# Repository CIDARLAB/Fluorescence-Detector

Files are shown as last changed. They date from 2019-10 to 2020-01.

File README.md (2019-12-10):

Fluorescence Detector

# Contents

1. Lockin-Amplifier - Full implementation of the Fluorescence Detector System
2. ADC Test Board - Test Board and default in sister board for ADC for V1 of the Lockin-Amplifier
3. Mod-Demod Test Board - Test board for the demodulator testing
4. Light Source Modulator Board - Board for Modulating the Light Source (LED/Laser)

# Locking Amplifier Specs

| Parameter 	| Value 	|
|---	|---	|
| #Channels 	| 1 	|
| Max Sampling Rate 	| 2.5 kHz 	|
| Amplification 	| x10^8 (140 dB) 	|
| SNR 	| TBA 	|
| Input Voltage Noise 	| TBA 	|
| Input Impedance 	| TBA 	|
| Voltage Sensitivity Range 	| TBA to TBA 	|
| Minimum Step Size 	| TBA 	|
| ADC Resolution 	| 16 bit 	|
| ADC Interface 	| SPI (2 wire) 	|
| Supply Voltage 	| 24 V 	|
| Supply Current 	| 300 mA 	|
| Supply Pin 	| 2.5 mm Barrel Jack 	|

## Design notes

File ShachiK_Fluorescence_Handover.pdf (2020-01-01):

## Fluorescence Detector on Chip Handover Notes

Shachi Khadilkar
Ph.: 6173787579
Email: shachivk@bu.edu

The Fluorescence detector on chip uses a lock-in amplification technique to amplify weak fluorescent signals obscured by noise. The object of this text is to briefly describe the different parts of this system and how to use them.

Big picture:

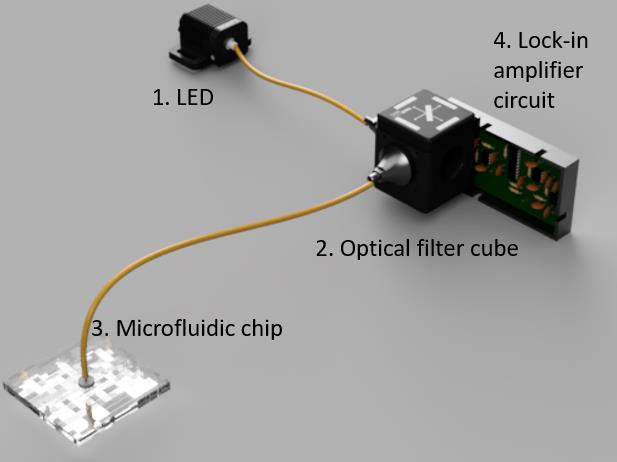
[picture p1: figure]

Electronics:

Lock-in amplification requires a modulated light source, pre-amplifiers and a demodulator + low pass filter circuit. Three PCBs were made – an LED modulator, a lock-in amplifier and an A to D board.

Lock-in amplifier PCB:

Components:
1. TL081 (4 ICs) – operational amplifiers
2. AD630 (1 IC) – Demodulator
3. Photodiode (1) – BPW21
4. Passives
5. Screw Terminals
6. Test points

Lock-in amplifier v1.1:

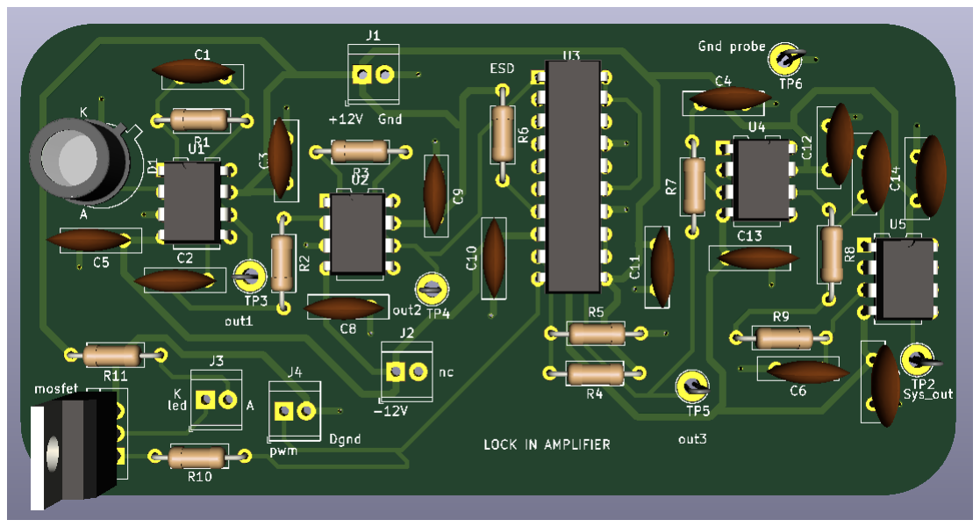
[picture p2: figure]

Using the board:

- Connect the power supply in series mode and supply power to the board at screw terminals with appropriate marking (+12V, -12V, Gnd). DO NOT exceed +-18V.
- Fluorescent light incident on the photodiode is the signal input to the PCB.
- The demodulator needs a PWM signal (at the screw term marked accordingly). Connect the Arduino ground to the Dgnd pin on the PCB. PWM signal is 5kHz, 10 % duty cycle for the current design.
- Output signal is obtained at test point Sys_out (or Final o/p for v1.2).
If the output signal is being measured by an oscilloscope, connect the scope probe to Sys_out and the ground clip to the test point labelled Gnd probe.
If ADC is used, connect Sys_out to ADC
- The test-point after each stage can be used for hardware debugging.

Lock-in amplifier v1.2:

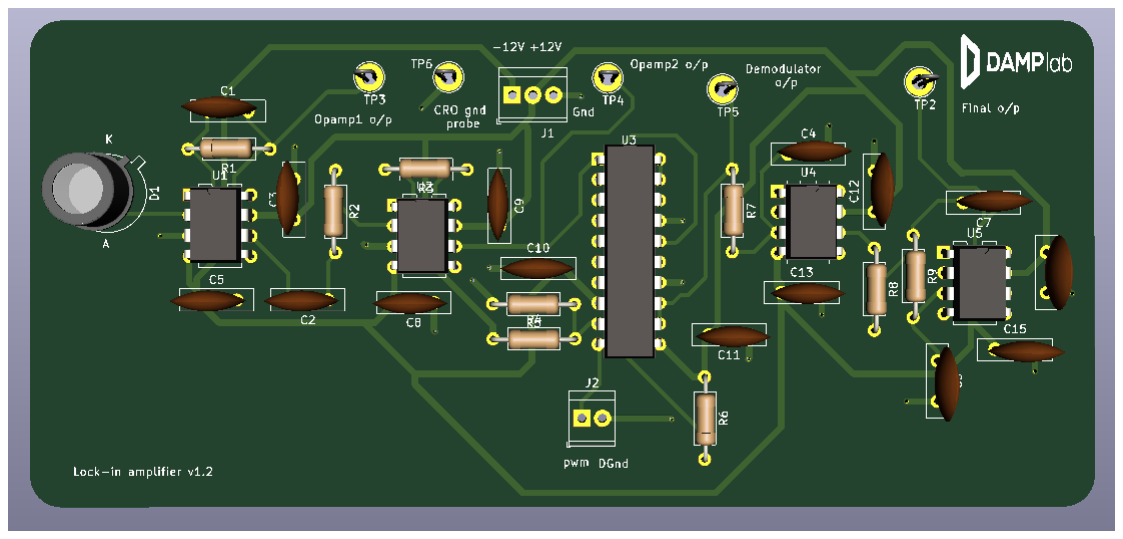
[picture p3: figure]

Using the board:

- Similar to v1.1.

A to D Converter:

Components:
1. AD8517 (1 IC) – A/D converter
2. OPA132 (1 IC) – Operational amplifier
3. Passives
4. Screw terminals

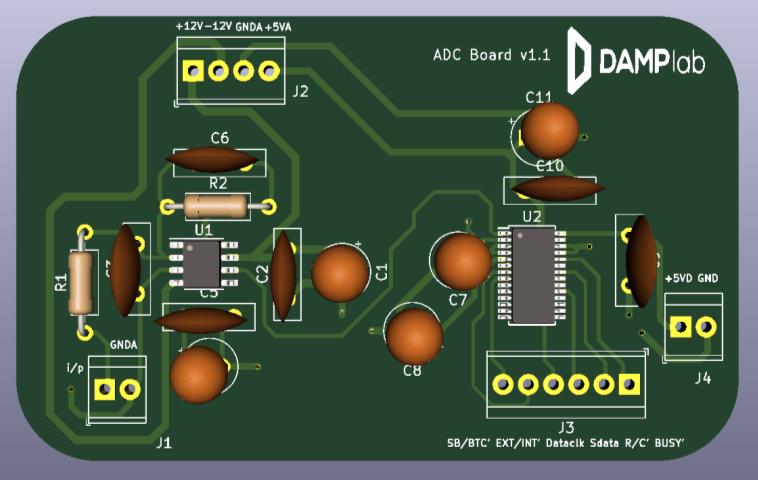
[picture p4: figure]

Using the board:

- Connect Sys_out (or Final o/p) of the lock-in amplifier board to appropriate screw terminal (marked i/p) for ADC analog input.
- Supply +-12V, ground, +5V analog and +1.8V digital power inputs to the board at the appropriate screw terminals. (Use 1.8VD where +5VD is marked)
- Connect digital ground to screw terminal J4 where indicated.
- SB/BTC’ (input): Set to high for straight binary format output. (Low gives binary twos complement)
- EXT/INT’ (input): Set to high to use the ADC as SPI slave. (Low to use ADC as SPI master).
- Dataclk (input): Clock from microcontroller.
- R/C’ (input): Use PWM to generate required signal (Refer to ADS8517 datasheet)
- Sdata (output): Serial data output synchronized to Dataclk.
- Busy’ (output): Busy’ goes low and stays low until conversion is complete.

Modulator:

Components:
1. FQP30N06L (1 IC) – Mosfet
2. Passives
3. Screw Terminals

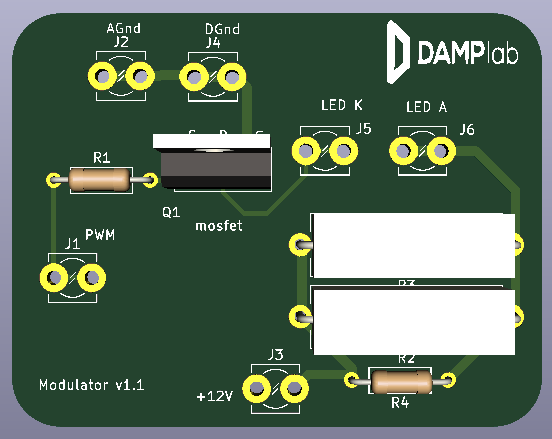
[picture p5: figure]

Using the board:

- Supply 12V, analog and digital ground to the board at appropriate screw terminal. The two high wattage resistors are 50 ohms each.
- Connect LED Anode and Cathode as indicated on the board.
- PWM for modulating the LED (5khz, 10 % duty cycle) should be given at screw terminal J1.
- Maximum allowable LED current is 700mA for M565F3.

Optics:

Components:
1. DFM1 (1) - Kinematic Fluorescence Filter Cube
2. CVH100-COL (2) – Couplers
3. LA1074 (2) – Collimators
4. MF620-52 (1) - TRITC/CY3.5 Emission Filter CWL = 620 nm, BW = 52 nm
5. MD568 (1) - TRITC Dichroic Filter, Refl. Band = 525-556 nm, Trans. Band = 580-650 nm
6. M28L01 (2) – SMA – SMA fiber patch cable
7. M565F3 (1) – 565 nm LED

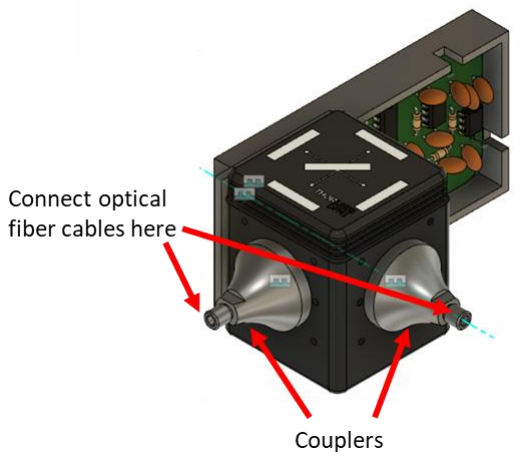
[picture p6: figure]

- A 13mW optical power LED is used as the light source for the system.
- A 30 mm kinematic fluorescence filter cube with an emission filter and a dichroic mirror is used. The filter cube is mounted on the case that holds the PCB. To change filters/ dichroic in the filter cube, refer to https://youtu.be/qWIfiwuL-gQ.
- Use retaining rings to fix the filters in place. (DAMP lab South has a spanner wrench for standard size filters)
- Optical couplers are compatible with filter cube and can be screwed in easily. Both couplers have been fitted with collimators.
- Use optical fiber cables to connect filter cube to microfluidic chip and light source (through the couplers).

Instructions for experiments:

- The setup should be placed on the ESD mat and user must wear the wrist strap to avoid damage to the ESD sensitive demodulator IC AD630 and photodiode BPW 21.
- Make connections to the modulator board and the lock-in amplifier board as described above.
- Connect LED to optical filter cube using fiber cable and coupler.
- Depending on number of optical interfaces to be used for the experiment use optical fibers, couplers etc. to capture fluorescent light from the sample.
- The current optical setup is chosen for reagent Amplex UltraRed. For spectrum see https://www.thermofisher.com/order/catalog/product/A36006#/A36006
- The final goal is to detect fluorescence from droplets in microfluidic chips. To find a lower limit of detection, a stationary cuvette (or droplets on a slide) may be used for testing by serially diluting the sample and measuring fluorescent signals for each concentration. (Eg. 1mM to 100nM)
- Connect the oscilloscope (as mentioned above) to measure the voltage proportional to each concentration.

Software used for PCB design: KiCad EDA (https://kicad-pcb.org/)
Software used for simulating the circuit: LTspice (https://www.analog.com/en/design-center/designtools-and-calculators/ltspice-simulator.html) (https://www.analog.com/en/design-center/design-tools-and-calculators/ltspice-simulator.html)

For LTspice Analysis refer to http://ltwiki.org/index.php?title=Simulation_Command,https://www.analog.com/en/technical-articles/ltspice-using-the-step-command-to-perform-repeatedanalysis.html (https://www.analog.com/en/technical-articles/ltspice-using-the-step-command-to-perform-repeated-analysis.html)

Status and Next Steps:

Part | Status | Issues | Potential Next Steps
Lock-in Amplifier Circuit | Working prototype Circuit output increases with increase in light incident on photodiode. (Expected behavior)
1. Noise-signal trade-
| | off (Low pass filtering cutoff frequency)
2. Low frequency noise
| | from amplifiers, passives.
3. Inability to operate
| | in ambient light.
1. Testing with
different
low pass
filter
frequencies
(eg 20Hz to
2.5kHz)
2. Replacing
existing
opamps
with lower
noise
alternatives
(eg.
OPA145)
3. Lockin
amplifier
multiplexing

Optical
setup
Prototyping | 1. LED power is very low (max 13mW)
2. Losses at each
| optical interface
3. LED is broadband
| and hence a very small fraction of light reaches the photodiode.
1. Light source
must have a
high optical
power and
should be
narrow band
(eg. LASER
diode)

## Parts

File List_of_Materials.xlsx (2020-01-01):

Component Name | Purpose | Quantity | Unit Cost | Total Cost
TL081 | Op-amps for Lock-in | 4 | 0.56 | 2.24
AD630 | Demodulator | 2 | 38.58 | 77.16
Test points | Hardware debugging | 6 | 0.25 | 1.5
BPW 21 | Photodiode | 2 | 12.57 | 25.14
Screw Terminals(6 pos) | Inputs, outputs to PCB | 1 | 4.72 | 4.72
Lock-in PCB cost |  |  |  | 22
ADS8517 | A/D Converter | 1 | 19.22 | 19.22
ADC PCB cost |  |  |  | 5
OPA132 | Buffer op-amp | 2 | 3.87 | 7.74
FQP30N06L | Mosfet for LED modulator | 1 | 1.22 | 1.22
Modulator PCB cost |  |  |  | 5
DFM1 | Kinematic Fluorescence filter cube | 1 | 386.17 | 386.17
CVH100-COL | Couplers to connect the filter cube to microfluidic chip/ light source | 2 | 100.1 | 200.2
LA1074 | Collimators | 1 | 22.62 | 22.62
MF620-52 | Emission filter | 1 | 257.54 | 257.54
MD568 | Dichroic mirror | 1 | 236.98 | 236.98
M28L01 | Fiber optic cable | 2 | 93.06 | 186.12
M565F3 | LED | 1 | 464.67 | 464.67
Passives | Resistors, Capacitors |  |  | 30
 |  |  | Total | 1955.24

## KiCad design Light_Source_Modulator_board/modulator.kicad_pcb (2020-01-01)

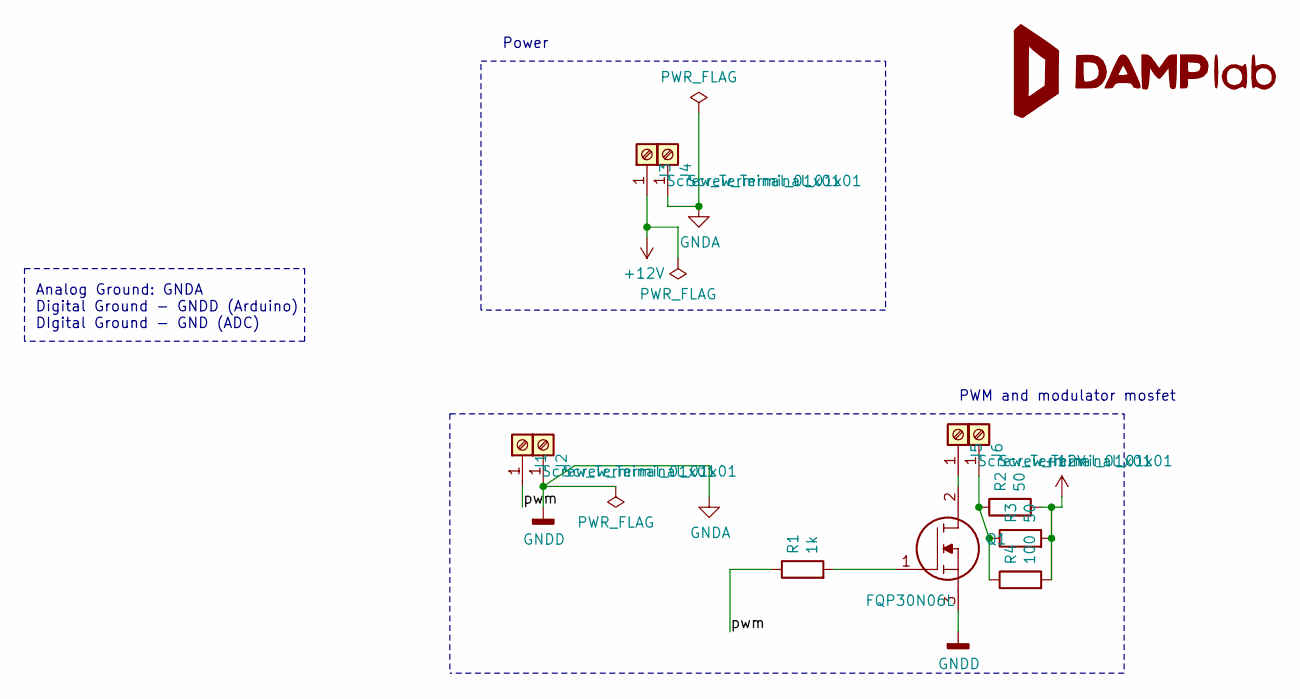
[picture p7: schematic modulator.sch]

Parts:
G1: LOGO; damp_logo
J1, J2, J3, J4, J5, J6: Screw_Terminal_01x01; TerminalBlock_MetzConnect_360381_1x01_Horizontal_ScrewM3.0
Q1: FQP30N06L; TO-220-3_Vertical; Mouser Part Number 512-FQP30N06L
R1: 1k; R_Axial_DIN0207_L6.3mm_D2.5mm_P10.16mm_Horizontal
R2, R3: 50; R_Axial_Power_L20.0mm_W6.4mm_P22.40mm
R4: 100; R_Axial_DIN0207_L6.3mm_D2.5mm_P10.16mm_Horizontal

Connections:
+12V: J3.1, R2.2, R3.2, R4.2
/pwm: J1.1, R1.1
GNDA: J2.1, J4.1, Q1.3
unnamed: J5.1, Q1.2
unnamed: J6.1, R2.1, R3.1, R4.1
unnamed: Q1.1, R1.2

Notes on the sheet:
PWM and modulator mosfet
Analog Ground: GNDA Digital Ground - GNDD (Arduino) DIgital Ground - GND (ADC)
Power

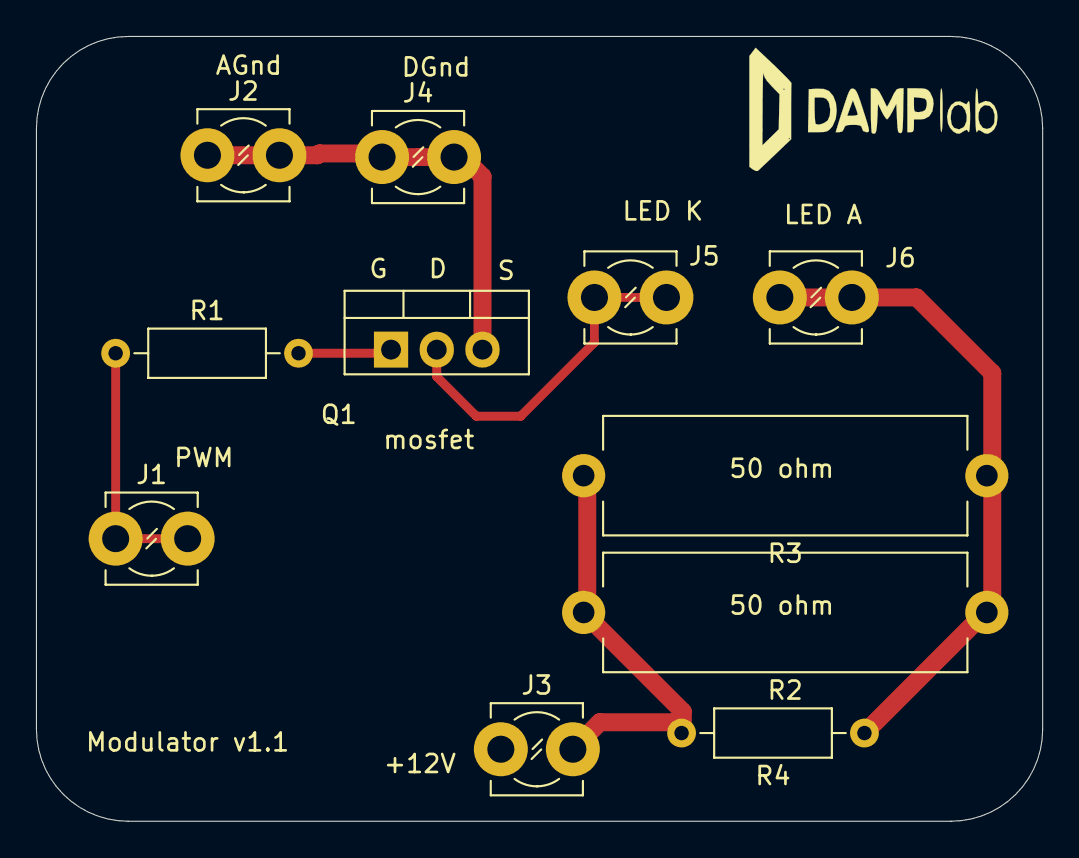
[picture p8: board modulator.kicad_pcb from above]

Board: 2 copper layers, 55.9 x 43.6 mm, 12 parts (0 on the bottom side), 6 nets.

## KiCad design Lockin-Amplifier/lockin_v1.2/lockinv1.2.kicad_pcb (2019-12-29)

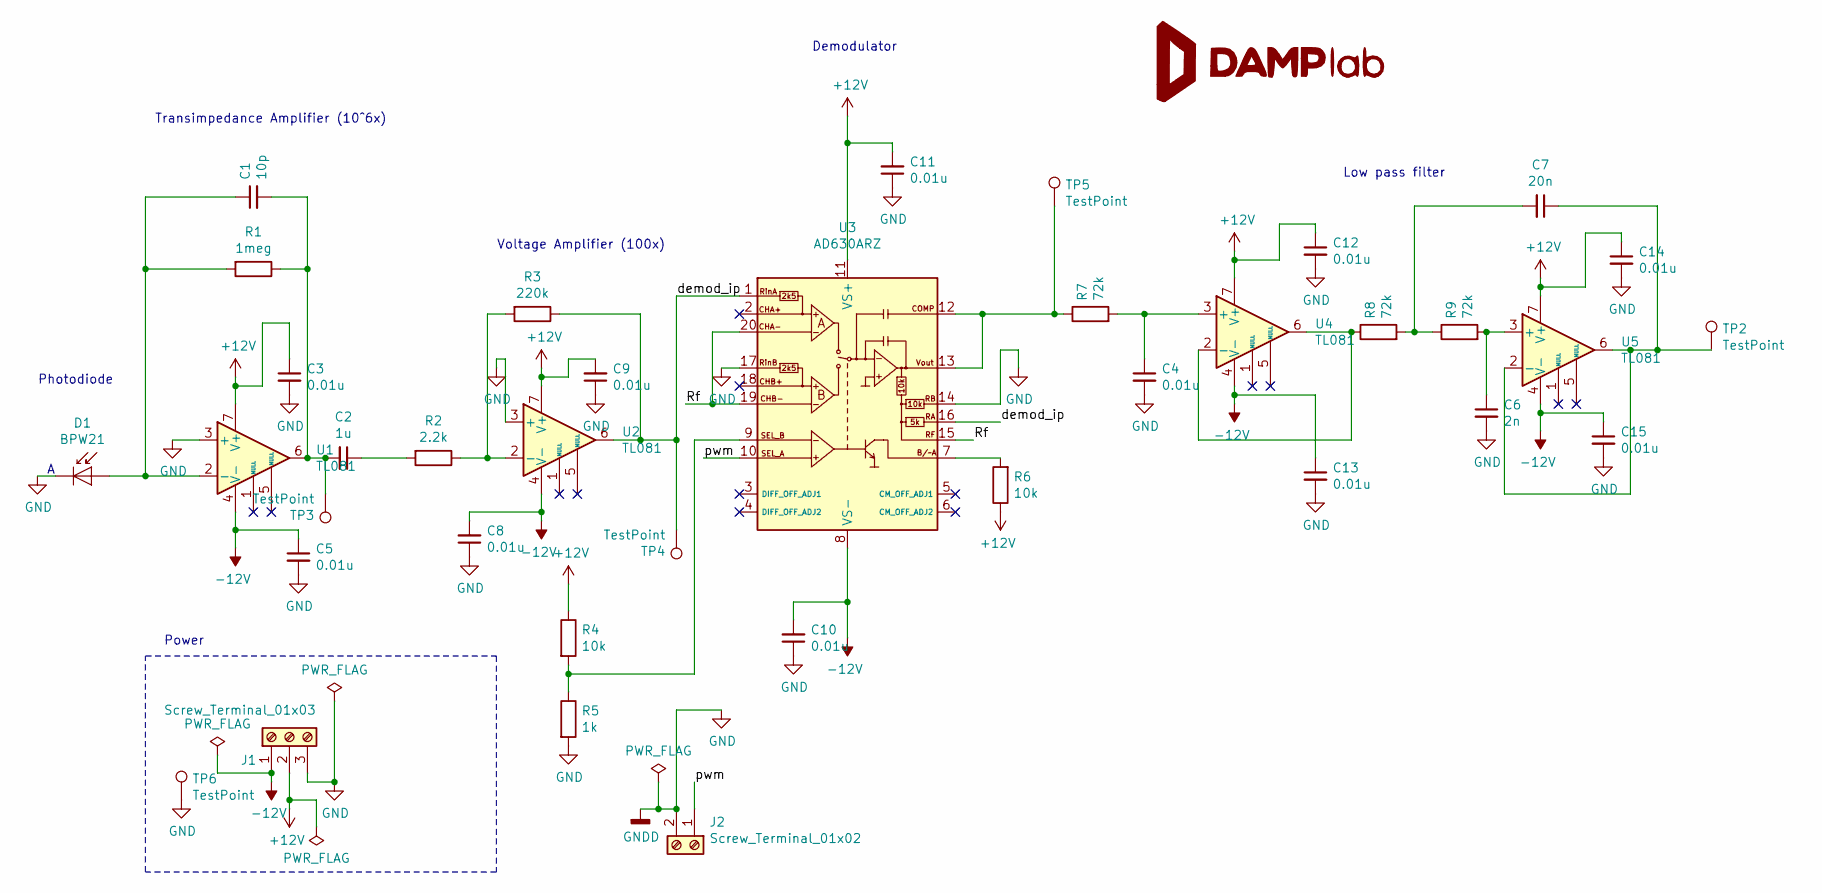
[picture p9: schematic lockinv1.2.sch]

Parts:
C1: 10p; C_Disc_D9.0mm_W2.5mm_P5.00mm
C2: 1u; C_Disc_D9.0mm_W2.5mm_P5.00mm
C3, C4, C5, C8, C9, C10, C11, C12, C13, C14, C15: 0.01u; C_Disc_D9.0mm_W2.5mm_P5.00mm
C6: 2n; C_Disc_D9.0mm_W2.5mm_P5.00mm
C7: 20n; C_Disc_D9.0mm_W2.5mm_P5.00mm
D1: BPW21; TO-5-2_Window
G1: LOGO; damp_logo
J1: Screw_Terminal_01x03; TerminalBlock_TE_282834-3_1x03_P2.54mm_Horizontal
J2: Screw_Terminal_01x02; TerminalBlock_TE_282834-2_1x02_P2.54mm_Horizontal
R1: 1meg; R_Axial_DIN0207_L6.3mm_D2.5mm_P10.16mm_Horizontal
R2: 2.2k; R_Axial_DIN0207_L6.3mm_D2.5mm_P10.16mm_Horizontal
R3: 220k; R_Axial_DIN0207_L6.3mm_D2.5mm_P10.16mm_Horizontal
R4, R6: 10k; R_Axial_DIN0207_L6.3mm_D2.5mm_P10.16mm_Horizontal
R5: 1k; R_Axial_DIN0207_L6.3mm_D2.5mm_P10.16mm_Horizontal
R7, R8, R9: 72k; R_Axial_DIN0207_L6.3mm_D2.5mm_P10.16mm_Horizontal
TP2, TP3, TP4, TP5, TP6: TestPoint; TestPoint_Loop_D2.50mm_Drill1.85mm
U1, U2, U4, U5: TL081; DIP-8_W7.62mm
U3: AD630ARZ; DIP-20_W7.62mm

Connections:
+12V: C3.1, C9.2, C11.2, C12.1, C14.1, J1.2, R4.1, R6.1, U1.7 (V+), U2.7 (V+), U3.11 (VS+), U4.7 (V+), U5.7 (V+)
-12V: C5.1, C8.2, C10.2, C13.1, C15.1, J1.1, U1.4 (V-), U2.4 (V-), U3.8 (VS-), U4.4 (V-), U5.4 (V-)
/Rf: U3.15 (RF), U3.19 (CHB-), U3.20 (CHA-)
/demod_ip: R3.1, TP4.1, U2.6, U3.1 (RinA), U3.16 (RA)
/pwm: J2.1, U3.10 (SEL_A)
GND: C3.2, C4.2, C5.2, C6.2, C8.1, C9.1, C10.1, C11.1, C12.2, C13.2, C14.2, C15.2, D1.1 (K), J1.3, J2.2, R5.2, TP6.1, U1.3 (+), U2.3 (+), U3.14 (RB), U3.17 (RinB)
unnamed: C1.1, D1.2 (A), R1.2, U1.2 (-)
unnamed: C1.2, C2.2, R1.1, TP3.1, U1.6
unnamed: C2.1, R2.2
unnamed: C4.1, R7.2, U4.3 (+)
unnamed: C6.1, R9.2, U5.3 (+)
unnamed: C7.1, TP2.1, U5.2 (-), U5.6
unnamed: C7.2, R8.2, R9.1
unnamed: R2.1, R3.2, U2.2 (-)
unnamed: R4.2, R5.1, U3.9 (SEL_B)
unnamed: R6.2, U3.7 (B/~A)
unnamed: R7.1, TP5.1, U3.12 (COMP), U3.13 (Vout)
unnamed: R8.1, U4.2 (-), U4.6

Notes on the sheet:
Demodulator
Low pass filter
Photodiode
Power
Voltage Amplifier (100x)
Transimpedance Amplifier (10^6x)

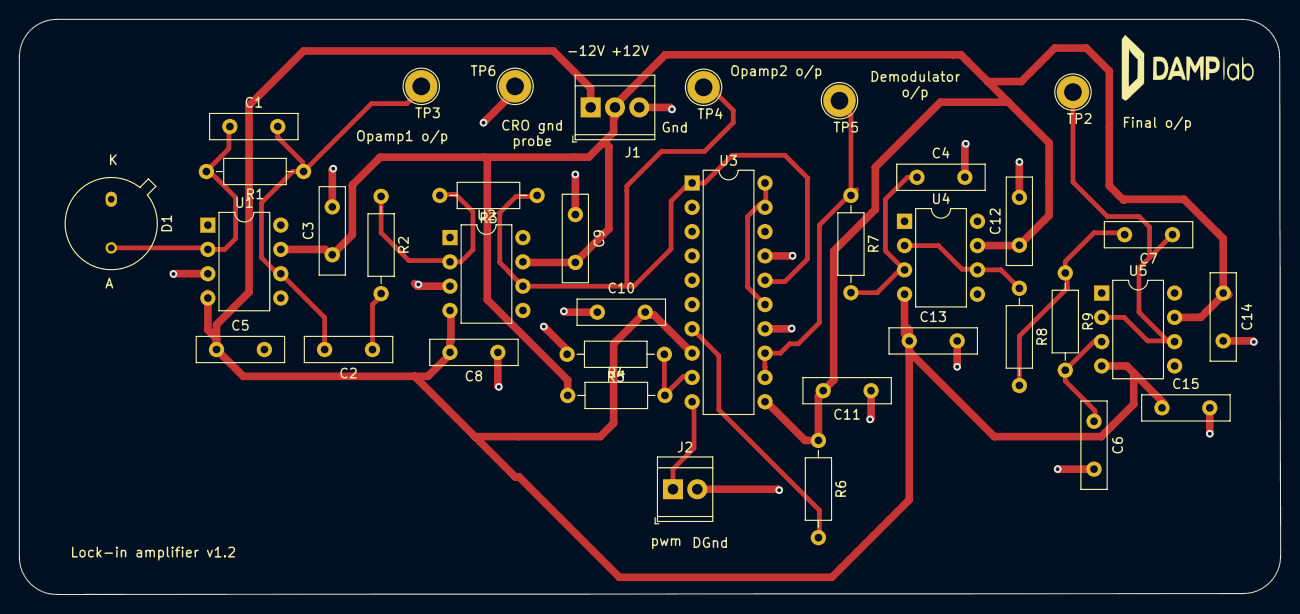
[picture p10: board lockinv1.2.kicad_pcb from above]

Board: 2 copper layers, 131.8 x 60.1 mm, 38 parts (0 on the bottom side), 18 nets.

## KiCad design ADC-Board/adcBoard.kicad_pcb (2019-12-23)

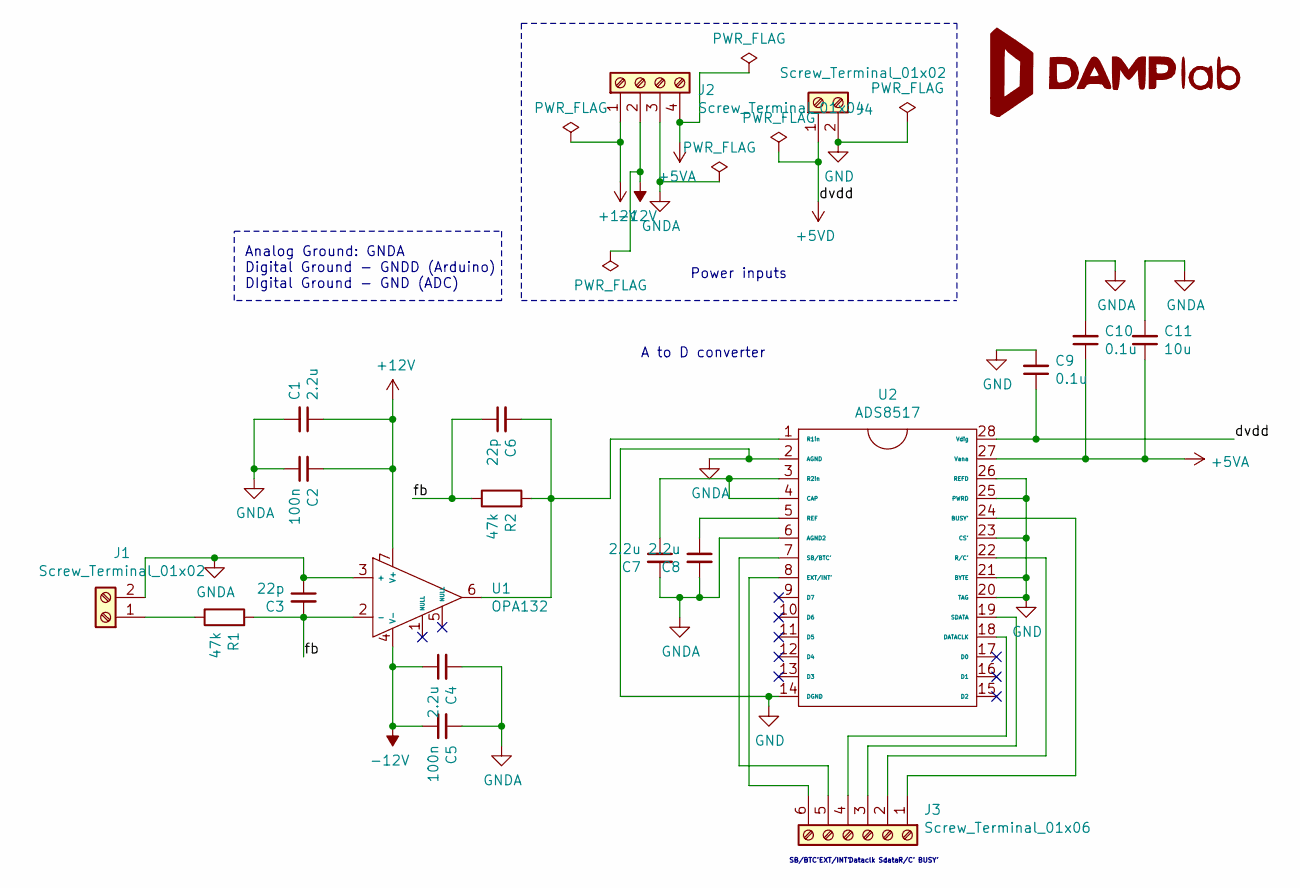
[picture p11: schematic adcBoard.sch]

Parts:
C1, C4, C7, C8: 2.2u; CP_Radial_Tantal_D5.5mm_P2.50mm
C2, C5: 100n; C_Disc_D9.0mm_W2.5mm_P5.00mm
C3, C6: 22p; C_Disc_D9.0mm_W2.5mm_P5.00mm
C9, C10: 0.1u; C_Disc_D9.0mm_W2.5mm_P5.00mm
C11: 10u; CP_Radial_Tantal_D5.5mm_P2.50mm
G1: LOGO; damp_logo
J1, J4: Screw_Terminal_01x02; TerminalBlock_TE_282834-2_1x02_P2.54mm_Horizontal
J2: Screw_Terminal_01x04; TerminalBlock_TE_282834-4_1x04_P2.54mm_Horizontal
J3: Screw_Terminal_01x06; TerminalBlock_TE_282834-6_1x06_P2.54mm_Horizontal
R1, R2: 47k; R_Axial_DIN0207_L6.3mm_D2.5mm_P10.16mm_Horizontal
U1: OPA132; SOIC-8_3.9x4.9mm_P1.27mm
U2: ADS8517; TSSOP-28_4.4x9.7mm_P0.65mm

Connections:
+5VA: C10.1, C11.1, J2.4, U2.27 (Vana)
+5VD: C9.1, J4.1, U2.28 (Vdig)
+12V: C1.1, C2.2, J2.1, U1.7 (V+)
-12V: C4.1, C5.1, J2.2, U1.4 (V-)
/fb: C3.2, C6.1, R1.2, R2.1, U1.2 (-)
GND: C1.2, C2.1, C3.1, C4.2, C5.2, C7.2, C8.2, C9.2, C10.2, C11.2, J1.2, J2.3, J4.2, U1.3 (+), U2.2 (AGND), U2.6 (AGND2), U2.14 (DGND), U2.20 (TAG), U2.21 (BYTE), U2.23 (CS'), U2.25 (PWRD), U2.26 (REFD)
unnamed: C6.2, R2.2, U1.6, U2.1 (R1in)
unnamed: C7.1, U2.3 (R2in), U2.4 (CAP)
unnamed: C8.1, U2.5 (REF)
unnamed: J1.1, R1.1
unnamed: J3.1, U2.24 (BUSY')
unnamed: J3.2, U2.22 (R/C')
unnamed: J3.3, U2.19 (SDATA)
unnamed: J3.4, U2.18 (DATACLK)
unnamed: J3.5, U2.7 (SB/BTC')
unnamed: J3.6, U2.8 (EXT/INT')

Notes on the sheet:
Analog Ground: GNDA Digital Ground - GNDD (Arduino) DIgital Ground - GND (ADC)
Power inputs
SB/BTC'
EXT/INT'
Dataclk
Sdata
R/C'
BUSY'
A to D converter

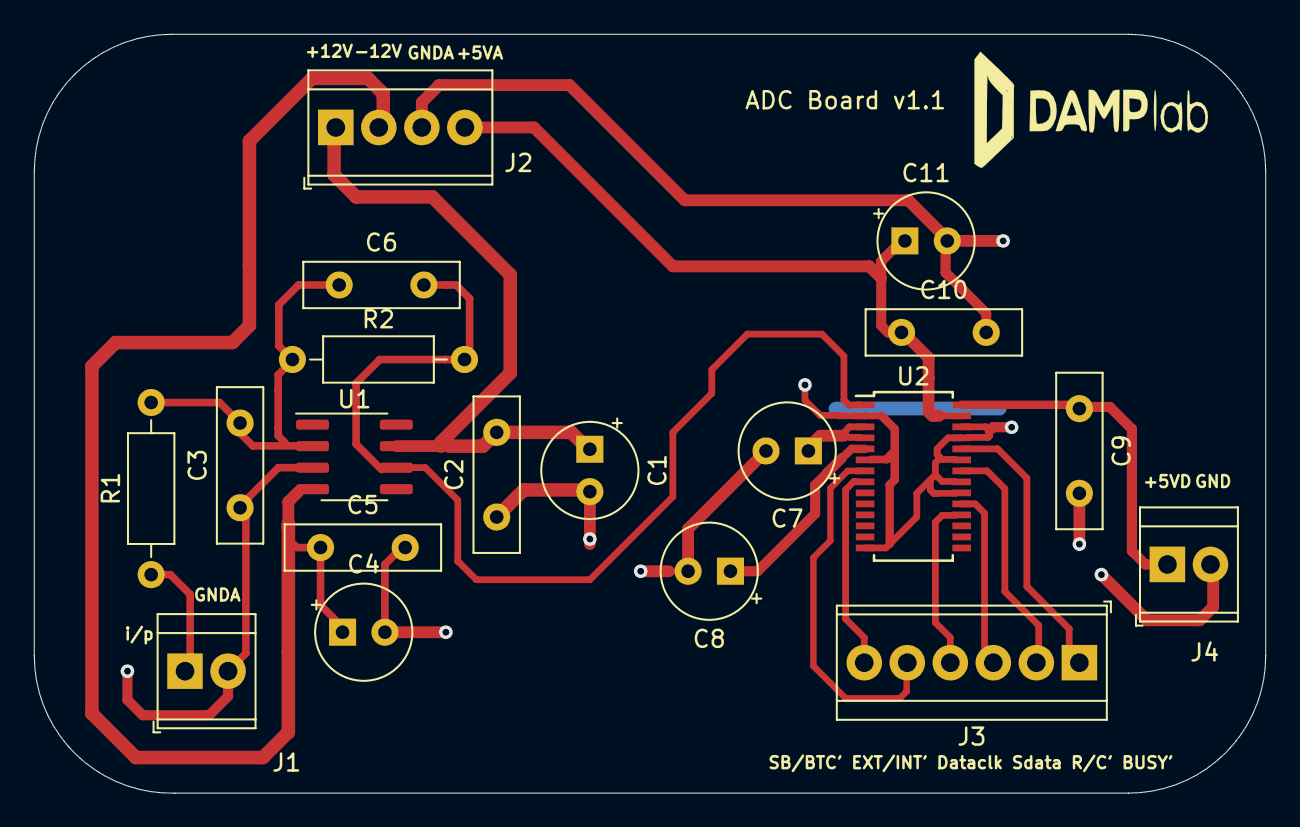
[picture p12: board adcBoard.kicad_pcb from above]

Board: 2 copper layers, 72.7 x 44.8 mm, 20 parts (0 on the bottom side), 16 nets.

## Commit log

2019-10-28 Lock in PCB v1.1
    [finalForLayout-B_Cu.gbl, finalForLayout-B_Mask.gbs, finalForLayout-B_Paste.gbp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]
2019-11-25 Rename folder
    [finalForLayout-B_Cu.gbl, finalForLayout-B_Mask.gbs, finalForLayout-B_Paste.gbp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]
2019-12-10 Renamed the folder to Lockin Amplifier
    [finalForLayout-B_Cu.gbl, finalForLayout-B_Mask.gbs, finalForLayout-B_Paste.gbp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]
2019-12-23 Adding ADC board v1.1
    [adcBoard-B_Cu.gbl, adcBoard-B_Mask.gbs, adcBoard-B_Paste.gbp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]
2019-12-23 Reverting to 5639559f49259e50b6b5cf6be8fd6d8661ee3bd0
    [adcBoard-B_Cu.gbl, adcBoard-B_Mask.gbs, adcBoard-B_Paste.gbp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]
2019-12-23 ADC Kicad files
    [adcBoard-B_Cu.gbl, adcBoard-B_Mask.gbs, adcBoard-B_Paste.gbp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]
2019-12-29 Rearranging lockin amp folder
    [finalForLayout-B_Cu.gbl, finalForLayout-B_Mask.gbs, finalForLayout-B_Paste.gbp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]
2019-12-29 Lock-in PCB v1.2
    [lockinv1.2.kicad_pcb, lockinv1.2.sch]
2020-01-01 Modulator Kicad files and gerbers
    [modulator-B_Cu.gbl, modulator-B_Mask.gbs, modulator-B_Paste.gbp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]
2020-01-01 Renamed modulator
    [modulator-B_Cu.gbl, modulator-B_Mask.gbs, modulator-B_Paste.gbp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]
2020-01-01 List of Materials
    [List_of_Materials.xlsx]
